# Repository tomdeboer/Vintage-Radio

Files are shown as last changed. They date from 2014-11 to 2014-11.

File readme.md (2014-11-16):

*Vintage Radio*
----
This project started out a birthday gift for a friend, but has changed shape many times over the years. The idea was to take a '60s vintage radio and upgrade it as well as I can with stereo, bluetooth, IR remote control, motorised volume knobs and quality >50 W speakers.

Now that the project is really taking shape, I thought: why not make the code and documents open source!

**Note: this is a work in progress at the moment.**

### What can it do?
As mentioned, the radio packs some serious punch when it comes to audio. It can play your tunes loudly and clearly. It also has a bluetooth receiver so you can stream your audio wirelessly. In addition to bluetooth, it has the standard red and white tulip audio jacks and a 3,5 mm audio/headphone jack. The headphone jack is actually an input and has some special functionality: it can mimic headphone controls. This means when you connect your phone to the radio via the headphone jack, your phone will think there's a headphone attached. Together with an infrared receiver, this allows your to control the volume or playback of your phone, as if you were touching the playback controls of your headphone. As a finishing touch, the vintage knobs turn a motorised potentiometer. So when you control the volume externally, i.e. using the remote, the knob will catch up with you and will turn to the appropriate position as if you were turning it yourself!

**Summing up:**

* \>50W audio amplifier
* Bluetooth audio
* Tulip audio connectors
* 3,5mm jack with headphone controls
* Infrared remote
* Self-turning volume knob!

### How do I use it?
The goal of this repository is to provide some sort of manual or inspiration for building your own upgraded vintage radio. It'll contain the Eagle board files of the PCB I designed for the project and there'll be links to all the datasheets you need. The board itself houses a Arduino Pro Mini 5V (for easy development) and contains digital pots for controlling the volume and controlling the headphone functionality. The bluetooth board is a separate RN52 break out board. I used the one from Spark Fun.

### Docs
[Arduino Pro mini](http://www.arduino.cc/en/Main/ArduinoBoardProMini)

[MCP41010 (digital pots)](http://ww1.microchip.com/downloads/en/DeviceDoc/11195c.pdf)

### BOM
- 1x Arduino Pro Mini $10
- 3x MCP41010 $1.50
- 6x 4.7k 5% resistor $1.50
- 10x Screw Terminals (2 conn) 3,5mm grid $5
- 4x Screw Terminals (3 conn) 3,5mm grid $2
- 1x 3.3V converter $2

*Total cost ~$25*

- '60s radio $20
- 35W Amplifier $60
- RN52 Bluetooth break out $40
- 50W JBL car Speakers $75

*Total: ~$195*

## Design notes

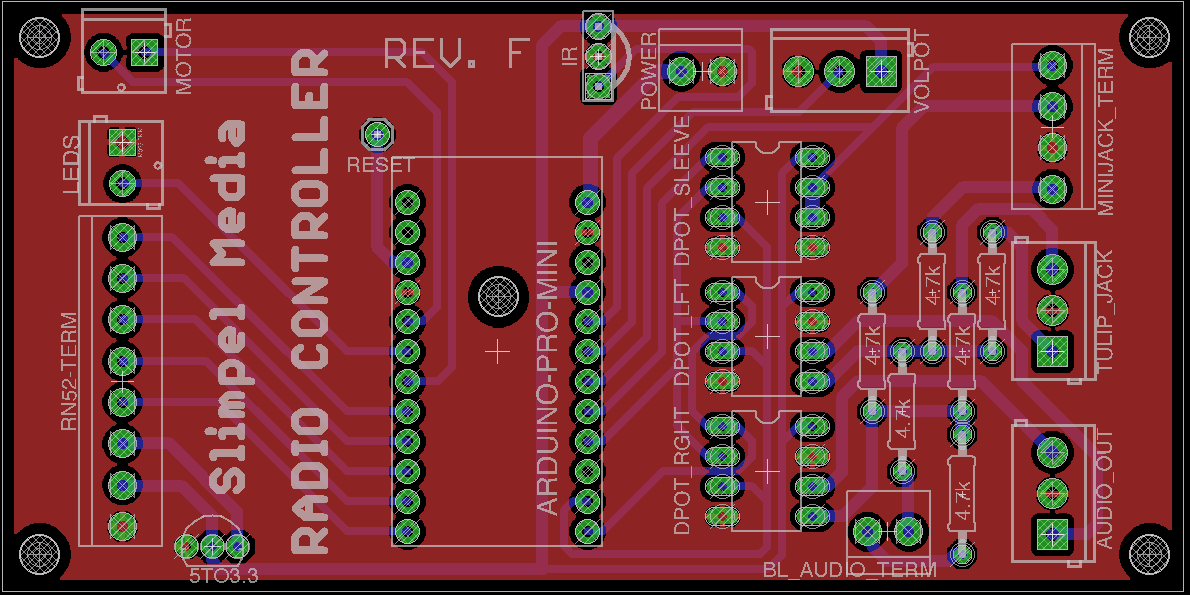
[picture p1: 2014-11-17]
Board/Screenshot.png

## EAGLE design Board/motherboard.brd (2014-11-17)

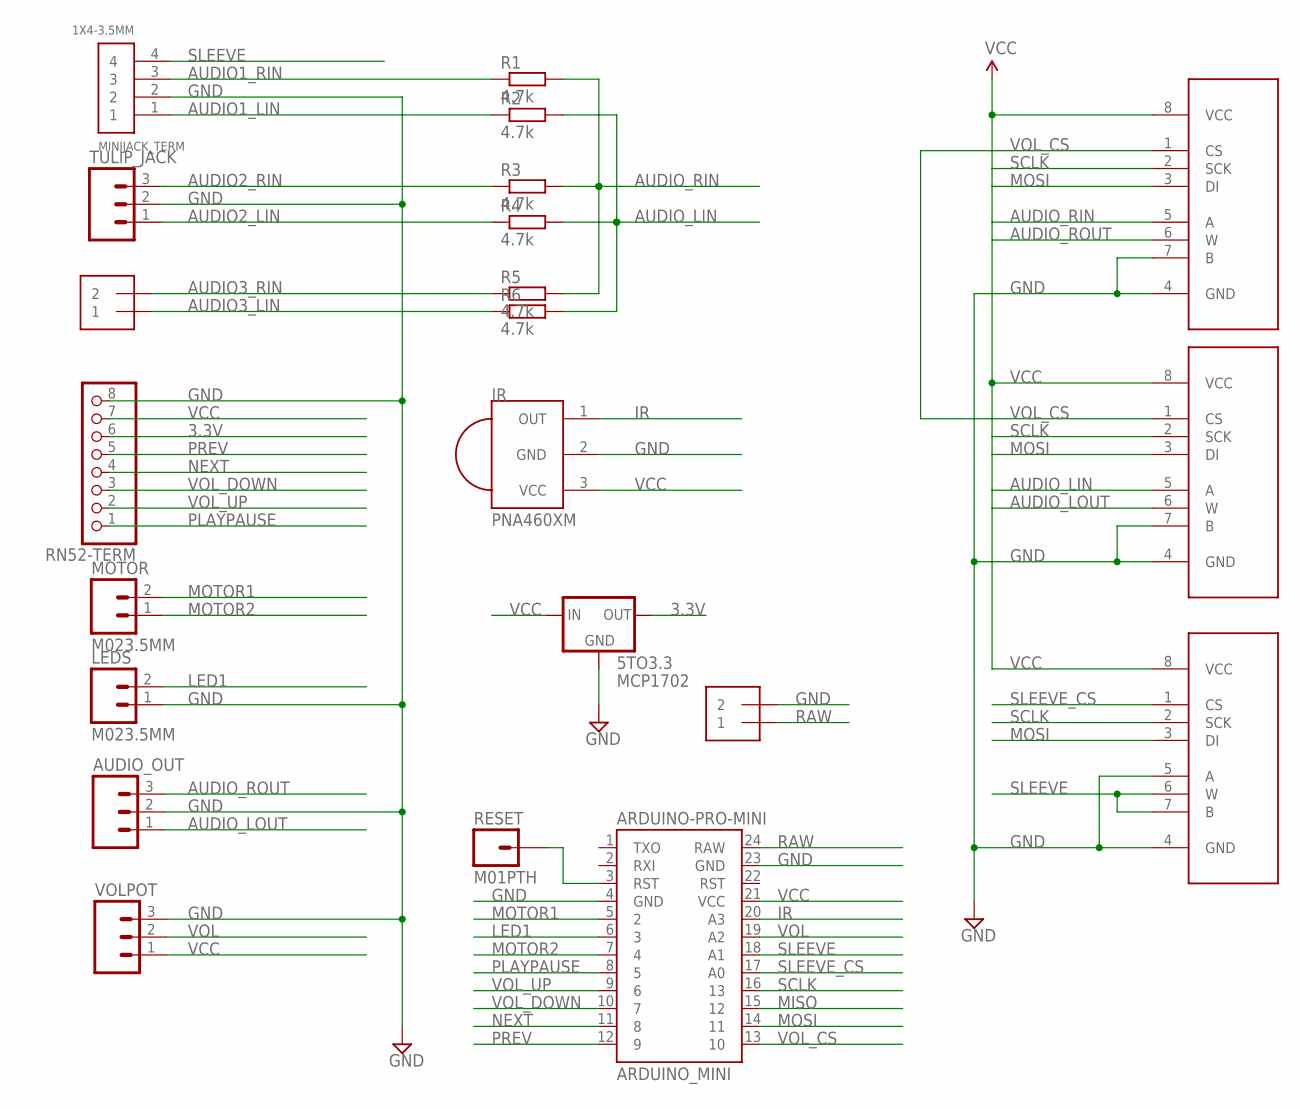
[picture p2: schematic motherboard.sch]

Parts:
5TO3.3: MCP1702; TO92-INLINE
ARDUINO-PRO-MINI: ARDUINO_MINI
AUDIO_OUT: M03SCREW; SCREWTERMINAL-3.5MM-3
BL_AUDIO_TERM: 1X2-3.5MM
DPOT_LFT: MCP41XXXDIL; DIL-08
DPOT_RGHT: MCP41XXXDIL; DIL-08
DPOT_SLEEVE: MCP41XXXDIL; DIL-08
IR: PNA460XM
LEDS: M023.5MM; SCREWTERMINAL-3.5MM-2
MINIJACK_TERM: 1X4-3.5MM; 1X04-3.5MM
MOTOR: M023.5MM; SCREWTERMINAL-3.5MM-2
POWER: 1X2-3.5MM
R1, R2, R3, R4, R5, R6: 4.7k; 0207/10
RESET: M01PTH; 1X01
RN52-TERM: PINHD-1X8-3.5MM; 1X08-3.5MM
TULIP_JACK: M03SCREW; SCREWTERMINAL-3.5MM-3
VOLPOT: M03SCREW; SCREWTERMINAL-3.5MM-3

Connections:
3.3V: 5TO3.3.3 (OUT), RN52-TERM.6
AUDIO1_LIN: MINIJACK_TERM.1, R2.1
AUDIO1_RIN: MINIJACK_TERM.3, R1.1
AUDIO2_LIN: R4.1, TULIP_JACK.1
AUDIO2_RIN: R3.1, TULIP_JACK.3
AUDIO3_LIN: BL_AUDIO_TERM.1, R6.1
AUDIO3_RIN: BL_AUDIO_TERM.2, R5.1
AUDIO_LIN: DPOT_LFT.5 (A), R2.2, R4.2, R6.2
AUDIO_LOUT: AUDIO_OUT.1, DPOT_LFT.6 (W)
AUDIO_RIN: DPOT_RGHT.5 (A), R1.2, R3.2, R5.2
AUDIO_ROUT: AUDIO_OUT.3, DPOT_RGHT.6 (W)
GND: 5TO3.3.1 (GND), ARDUINO-PRO-MINI.4 (GND), ARDUINO-PRO-MINI.23 (GND), AUDIO_OUT.2, DPOT_LFT.4 (GND), DPOT_LFT.7 (B), DPOT_RGHT.4 (GND), DPOT_RGHT.7 (B), DPOT_SLEEVE.4 (GND), DPOT_SLEEVE.5 (A), IR.2 (GND), LEDS.1, MINIJACK_TERM.2, POWER.2, RN52-TERM.8, TULIP_JACK.2, VOLPOT.3
IR: ARDUINO-PRO-MINI.20 (A3), IR.1 (OUT)
LED1: ARDUINO-PRO-MINI.6 (3), LEDS.2
MISO: ARDUINO-PRO-MINI.15 (12)
MOSI: ARDUINO-PRO-MINI.14 (11), DPOT_LFT.3 (DI), DPOT_RGHT.3 (DI), DPOT_SLEEVE.3 (DI)
MOTOR1: ARDUINO-PRO-MINI.5 (2), MOTOR.2
MOTOR2: ARDUINO-PRO-MINI.7 (4), MOTOR.1
unnamed: ARDUINO-PRO-MINI.3 (RST), RESET.1
NEXT: ARDUINO-PRO-MINI.11 (8), RN52-TERM.4
PLAYPAUSE: ARDUINO-PRO-MINI.8 (5), RN52-TERM.1
PREV: ARDUINO-PRO-MINI.12 (9), RN52-TERM.5
RAW: ARDUINO-PRO-MINI.24 (RAW), POWER.1
SCLK: ARDUINO-PRO-MINI.16 (13), DPOT_LFT.2 (SCK), DPOT_RGHT.2 (SCK), DPOT_SLEEVE.2 (SCK)
SLEEVE: ARDUINO-PRO-MINI.18 (A1), DPOT_SLEEVE.6 (W), DPOT_SLEEVE.7 (B), MINIJACK_TERM.4
SLEEVE_CS: ARDUINO-PRO-MINI.17 (A0), DPOT_SLEEVE.1 (CS)
VCC: 5TO3.3.2 (IN), ARDUINO-PRO-MINI.21 (VCC), DPOT_LFT.8 (VCC), DPOT_RGHT.8 (VCC), DPOT_SLEEVE.8 (VCC), IR.3 (VCC), RN52-TERM.7, VOLPOT.1
VOL: ARDUINO-PRO-MINI.19 (A2), VOLPOT.2
VOL_CS: ARDUINO-PRO-MINI.13 (10), DPOT_LFT.1 (CS), DPOT_RGHT.1 (CS)
VOL_DOWN: ARDUINO-PRO-MINI.10 (7), RN52-TERM.3
VOL_UP: ARDUINO-PRO-MINI.9 (6), RN52-TERM.2

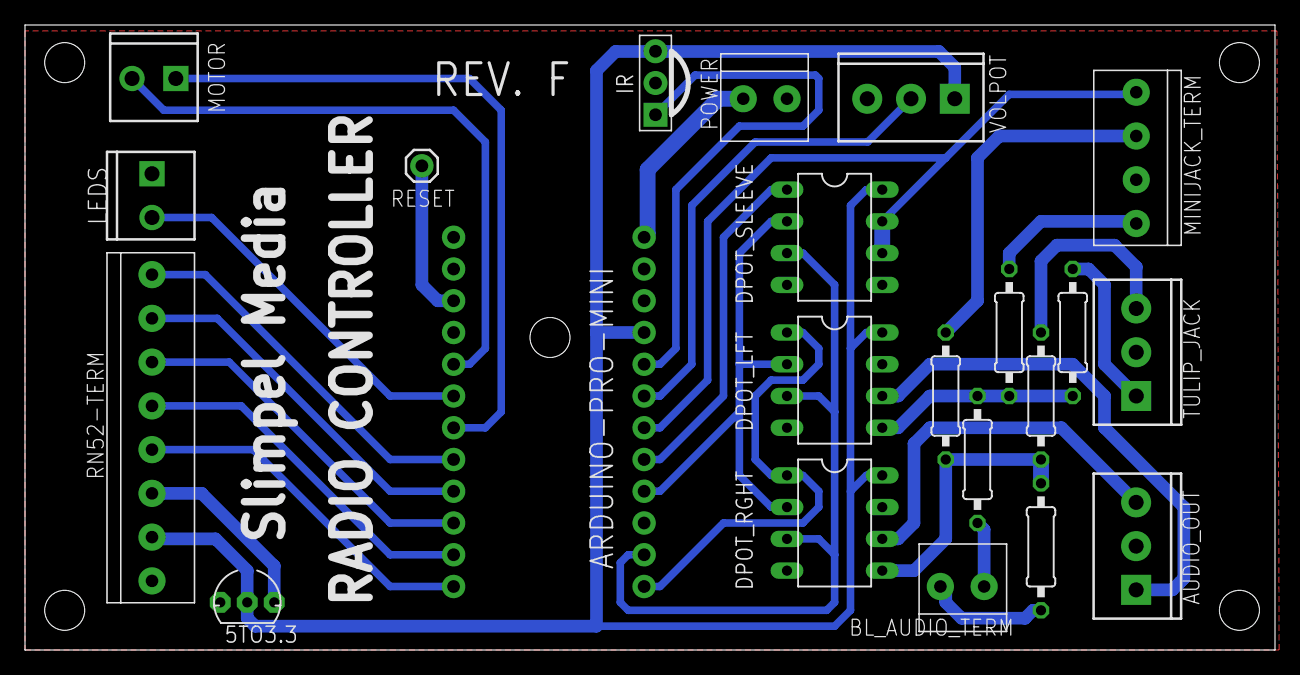
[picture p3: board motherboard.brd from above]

Board: 2 copper layers, 100.0 x 50.0 mm, 22 parts (0 on the bottom side), 30 nets.

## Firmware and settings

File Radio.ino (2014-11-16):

#include <Sheduler.h>
#include <IRremote.h>
#include <SPI.h>

// Led's
#define LED_STEP_SIZE 2
#define PIN_LEDS 3

// IR
#define PIN_IR A3


// Audio digital pot
#define PIN_AUDIO_SL 10
#define PIN_AUDIO_VOL A2
enum volume_source_e { EXTERNAL_SOURCE = 0, KNOB = 1 } volume_source = EXTERNAL_SOURCE;


// Sleeve digital pot
#define PIN_SLEEVE_SL A0
#define PIN_SLEEVE    A1 // This pin is set as input to shorten the mini-jack sleeve pin (used for play/pause toggling)
#define SLEEVE_ANALOG_TRESHOLD 300

typedef enum { CMD_OPEN, CMD_PLAY_PAUSE, CMD_PREV, CMD_NEXT } sleev_command_t;
#define CMD_PREV_RESISTANCE 240 // 240 Ohms
#define CMD_NEXT_RESISTANCE 600 // 600 Ohms

// Motor
#define PIN_MOTOR1 2
#define PIN_MOTOR2 4

typedef enum { MOTOR_CLOCKWISE = 1, MOTOR_ANTI_CLOCKWISE = 2, MOTOR_OFF = 0 } motor_setting_e;

typedef struct {
	uint8_t pin;
	uint8_t value;
	uint8_t target;
} LED_t;
LED_t backlight = {PIN_LEDS, 0, 0};

struct volume_t{
	uint8_t target;
	uint8_t value;
} volume = {0,0};

Sheduler sheduler;

uint8_t i;// Shared iterator
uint8_t adjust_speed = 2;

enum run_mode_e { STANDBY, RUNNING }
run_mode = STANDBY;

void mode_set (run_mode_e _mode) {
	if (_mode == STANDBY) {
		// Dim the volume
		volume_set_target(0);

		// Dim the lights
		backlight_set_target(0);

	} else if (_mode == RUNNING) {
		run_mode = RUNNING;
		backlight_randomize();
	}

	run_mode = _mode;
}

void task_backlight_rotate(Task* self){
	if (backlight.target == 0 && backlight.value == 0) {
		return;
	}

	if (backlight.target == backlight.value){
		backlight_randomize();
	}

	// If target is higher: step up
	if (backlight.target > backlight.value) {
		backlight.value += min(LED_STEP_SIZE, backlight.target - backlight.value);
	
	// If Lower: step down
	} else {
		backlight.value -= min(LED_STEP_SIZE, backlight.value - backlight.target);
	}

	backlight_write_value();
}
void backlight_set_value( uint8_t __val){
	backlight.value  = __val;
	// Serial.print("set led "); Serial.print(__led); Serial.print(" @ ");Serial.println(__val);
}
void backlight_set_target(uint8_t __val){
	backlight.target  = __val;
	volume.target = __val;
	// Serial.print("LED target: "); Serial.println(__val);
}
void backlight_write_value(){
	// Serial.print("LED write: "); Serial.println(backlight.value);
	analogWrite(backlight.pin, backlight.value);
}
void backlight_randomize(){
	backlight_set_target(random(1,255));
}

IRrecv irrecv(PIN_IR);
decode_results results;
void task_ir_read(Task* self){

	static uint32_t previous_value;

	if (irrecv.decode(&results) && results.value > 0x1FE0000 && results.value < 0x1FEFFFF ) {
		Serial.println(results.value, HEX);

		if ( results.value == ~0x0)
			results.value = previous_value;

		switch(results.value){
			case 0x1FE58A7: // MODE
				task_backlight_rotate(NULL);
				break;
			case 0x1FE609F:  // VOL_UP
				volume_increase();
				break;
			case 0x1FEA05F: // VOL_DOWN
				volume_decrease();
				break;
			case 0x1FE807F: // PLAY/PAUSE
				sleeve_command_send(CMD_PLAY_PAUSE);
				break;
			case 0x1FEC03F: // NEXT
				sleeve_command_send(CMD_NEXT);
				break;
			case 0x1FE40BF: // PREVIOUS
				sleeve_command_send(CMD_PREV);
				break;
			case 0x1FE48B7: // ON / OFF
				if( run_mode == STANDBY ){
					mode_set( RUNNING );
				}else{
					mode_set( STANDBY );
				}
				self->idle_cycles = 1500;
				break;
		}

		// Flash LED's
		analogWrite(backlight.pin, backlight.value < 64 ? 200 : 0 );
		delay(50);
		analogWrite(backlight.pin, backlight.value);

		previous_value = results.value;
		irrecv.resume(); // Receive the next value
	}
}

void volume_set_target(uint8_t __vol){
	volume.target = __vol;
}
void volume_increase(){
	if( volume.target <= (255-8)) volume.target += 8;
	volume_source = EXTERNAL_SOURCE;
}
void volume_decrease(){
	if( volume.target >= 8) volume.target -= 8;
	volume_source = EXTERNAL_SOURCE;
}

void task_volume_adjust(Task* self){
	if (volume.target == volume.value) return;

	if( volume.target > volume.value ){
		volume.value += min(adjust_speed, volume.target - volume.value);
	}else{
		volume.value -= min(adjust_speed, volume.value - volume.target);
	}

	audio_digipot_write(volume.value);
}

uint8_t stabalizer = 0; // Used for pot settling after

uint8_t read_volume_pot(){
	static int16_t last_value, value;
	if( value = analogRead(PIN_AUDIO_VOL), value < 10 || abs( last_value - value) > 10)
		last_value = value;
	
	return last_value >> 2;
}

void task_volume_adjust_pot(Task* self){
	if ( volume_source == KNOB){
		if ( run_mode != RUNNING ) return;
		volume.target = read_volume_pot();
	}else{
		uint8_t pot_value = read_volume_pot();
		if ( (pot_value >> 3) != (volume.target >> 3)){ // 8 bits  - 3 bits = 5 bits precision
			
			// Reset stabalizer
			stabalizer = 0;

			if (pot_value < volume.target){
				motor_set(MOTOR_CLOCKWISE);
			}else if (pot_value > volume.target){
				motor_set(MOTOR_ANTI_CLOCKWISE);
			}
		}else{
			motor_set(MOTOR_OFF);
			stabalizer += 1;
			if (stabalizer == 10) {
				// volume_source = KNOB;
				stabalizer = 0;
			}
		}
	}
}

bool    last_phone_connected    = false;
uint8_t phone_connected_counter = 0;

void task_detect_sleeve(Task* self){

	if ( phone_connected_counter < 5 && analogRead(PIN_SLEEVE) > SLEEVE_ANALOG_TRESHOLD ){
		phone_connected_counter += 1;
	}else if (phone_connected_counter > 0 && analogRead(PIN_SLEEVE) <= SLEEVE_ANALOG_TRESHOLD ) {
		phone_connected_counter -= 1;
	}
	// Serial.print("Phone sleeve value: "); Serial.println(analogRead(SLEEVE_SHORTING_PIN) );
	// Serial.print("Phone connected counter: "); Serial.println(phone_connected_counter);


	bool phone_connected = last_phone_connected ? (phone_connected_counter != 0) : (phone_connected_counter == 5);
	

	if ( phone_connected != last_phone_connected ){
		Serial.println(phone_connected ? "Phone connected" : "Phone not connected");
	
		if (run_mode == STANDBY && phone_connected){
			mode_set(RUNNING);
		}else if (run_mode == RUNNING && phone_connected == false){
			mode_set(STANDBY);
		}

		last_phone_connected = phone_connected;
	}
}

void print_status(Task* self){
	Serial.print("Run mode:"); Serial.println(run_mode);

	Serial.print("Volume source:"); Serial.println(volume_source);
	Serial.print("Volume target:"); Serial.println(volume.target);
	Serial.print("Volume volume:"); Serial.println(volume.value);
	Serial.print("Volume knob  :"); Serial.println((analogRead(PIN_AUDIO_VOL)));

	Serial.print("Sleeve       :"); Serial.println(analogRead(PIN_SLEEVE));
}

void setup() {
	Serial.begin(57600);

	// BACKLIGHT
	pinMode(backlight.pin, OUTPUT);
	backlight.value  = 0;
	backlight.target = 0;
	for(i = 0; i < 255; ++i){
		analogWrite(backlight.pin, i);
		delay(1);
	}
	for(i = 255; i > 0; --i){
		analogWrite(backlight.pin, i);
		delay(1);
	}
	delay(1000);



	// VOLUME DIGIPOTS
	digitalWrite(PIN_AUDIO_SL, HIGH);  // HIGH -= NOT active
	pinMode (PIN_AUDIO_SL, OUTPUT);

	// SLEEVE DIGIPOT
	digitalWrite(PIN_SLEEVE_SL, HIGH); // HIGH -= NOT active
	pinMode (PIN_SLEEVE_SL, OUTPUT);

	// SLEEVE ANALOG
	pinMode (PIN_SLEEVE, INPUT);
	digitalWrite(PIN_SLEEVE, LOW);


	// Start SPI and initialize
	SPI.begin();
	// audio_digipot_write(0);
	// sleeve_command_write(CMD_OPEN);
	// delay(3000);
	// sleeve_command_write(CMD_PLAY_PAUSE);
	// delay(3000);
	// sleeve_command_write(CMD_PREV);
	// delay(3000);
	// sleeve_command_write(CMD_NEXT);
	// delay(3000);
	// sleeve_command_write(CMD_OPEN);

	// IR
	irrecv.enableIRIn(); // Start the receiver

	// MOTOR
	Serial.print("Motor init...");
	pinMode(PIN_MOTOR1, OUTPUT);
	pinMode(PIN_MOTOR2, OUTPUT);
	Serial.print('.');
	motor_set(MOTOR_ANTI_CLOCKWISE);
	delay(1000);
	Serial.print('.');
	motor_set(MOTOR_CLOCKWISE);
	delay(500);
	Serial.print('.');
	Serial.println("DONE");



	// sheduler.addTask(task_ir_read, 100, false);

	sheduler.addTask(task_backlight_rotate, 30, false);

	sheduler.addTask(task_volume_adjust, 10, true);
	sheduler.addTask(task_volume_adjust_pot, 10, true);

	sheduler.addTask(task_detect_sleeve, 100, false);

	sheduler.addTask(print_status, 2000, true);

	// // Setup Timer1 for the sheduler,
	// // Every 1 millisecond.
	// TCCR1A  = 0x00;
	// TCCR1B  = (1 << WGM12) | (1 << CS10) | (1 << CS11); // Set prescaler to 64.
	// OCR1A   = 250;                                      // 16Mhz / 16 / 1000ms = 250 ticks.
	// TIMSK1 |= (1 << OCIE1A);                            // Set the ISR COMPA vect.

	mode_set(RUNNING);

	Serial.println("Setup done");
}

void audio_digipot_write(uint8_t value){
	// // High resistance == low volume, so flip value around
	// value = ( 255-value );

	digitalWrite(PIN_AUDIO_SL, LOW);
	if( value > 0){
		SPI.transfer(0x11); // Write to potentiometer
		SPI.transfer(value);
	}else{
		SPI.transfer(0x21); // Shutdown. Shorts B (audio out) & W (GND) together and cuts A (audio in) loose.
		SPI.transfer(0xFF); // Dummy resistance
	}
	digitalWrite(PIN_AUDIO_SL, HIGH);

	// digitalWrite(AUDIO_SLAVE_SELECT_PIN, LOW);
	// SPI.transfer(0x12); // Write data to potentiometer 1
	// SPI.transfer(value);
	// digitalWrite(AUDIO_SLAVE_SELECT_PIN, HIGH);
}

void sleeve_command_send(sleev_command_t command){
	sleeve_command_write(command);
	delay(200);
	sleeve_command_write(CMD_OPEN);
}

void sleeve_command_write(sleev_command_t command){


	Serial.print("Sleeve command "); Serial.println(command);

	digitalWrite(PIN_SLEEVE_SL, LOW);

	switch(command){
		case CMD_OPEN:
			Serial.print("OPEN "); Serial.println("-------");
			SPI.transfer(0x21); // Shutdown. Shorts B (not connected) & W (GND) together and cuts A (Sleeve) loose.
			SPI.transfer(0x0); // Dummy resistance
			pinMode(PIN_SLEEVE, INPUT);
			break;
		case CMD_PLAY_PAUSE:
			Serial.print("Pause "); Serial.println("0  ohm");
			SPI.transfer(0x11); // Write data:
			SPI.transfer(255-0);    // Short it (this makes it play/pause)
			pinMode(PIN_SLEEVE, OUTPUT);
			break;
		case CMD_PREV:
			Serial.print("PREV "); Serial.println("235 ohm");
			SPI.transfer(0x11); // Write data:
			// SPI.transfer(255*(CMD_PREV_RESISTANCE/10000));
			SPI.transfer(255-(6-2));
			pinMode(PIN_SLEEVE, INPUT);
			break;
		case CMD_NEXT:
			Serial.print("CMD_NEXT "); Serial.println("588 ohm");
			SPI.transfer(0x11); // Write data:
			SPI.transfer(255-(15-2));
			pinMode(PIN_SLEEVE, INPUT);
			break;
	}
	
	digitalWrite(PIN_SLEEVE_SL, HIGH);
}

void motor_set(motor_setting_e __setting){
	digitalWrite(PIN_MOTOR1, __setting == MOTOR_CLOCKWISE);
	digitalWrite(PIN_MOTOR2, __setting == MOTOR_ANTI_CLOCKWISE);
	// Serial.print("Direction: "); Serial.println(__setting);
}


unsigned long int last_ms = 0, ms = 0;

void loop() {
	if ( ms = millis(), ms != last_ms ){
		sheduler.tick();
		sheduler.run(); 
		last_ms = ms;
	}
}

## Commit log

2014-11-16 First commit
    Lots to be done! Not working entirely.
    [Radio.ino]
2014-11-16 Fixed motor controlling
2014-11-17 Added docs and board
    [motherboard.brd, motherboard.sch]

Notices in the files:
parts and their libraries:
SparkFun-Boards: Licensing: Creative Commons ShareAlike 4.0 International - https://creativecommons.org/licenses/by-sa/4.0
